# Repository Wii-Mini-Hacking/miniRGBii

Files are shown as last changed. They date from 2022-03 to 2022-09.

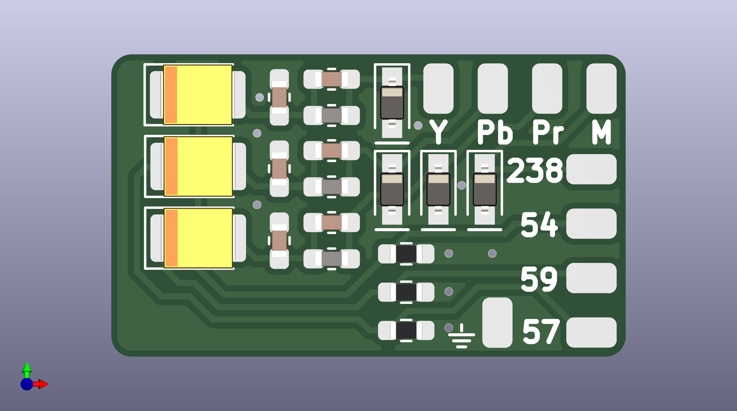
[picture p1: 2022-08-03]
images/miniRGBii_model_front_components.png

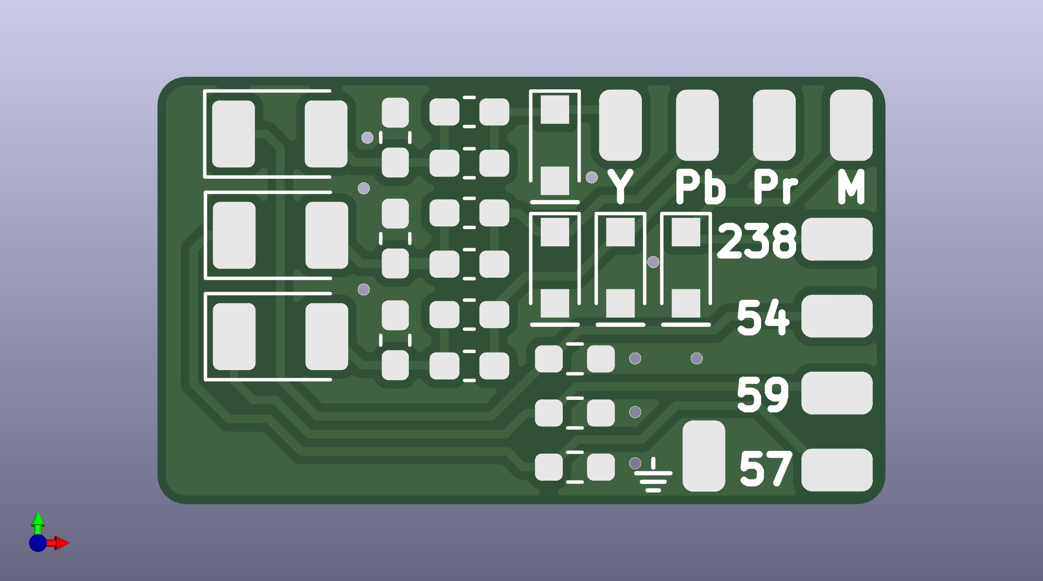
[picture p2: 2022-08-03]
images/miniRGBii_model_front.png

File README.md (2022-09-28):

# miniRGBii
Add-on Board that allows for the re-addition of component video/480p output on a Wii Mini (KiCAD format)

Designed by [@jobfeikens](https://github.com/jobfeikens) and [@Devnol](https://github.com/Devnol)

## Where to buy

You can currently order the miniRGBii directly from Devnol on [Tindie](https://www.tindie.com/products/27985/)

## Installation instructions

You can find instructions on installing the miniRGBii as well as a bunch of other Wii mini mods on [Pimp-My-Mini](https://wii-mini-hacking.github.io/Pimp-My-mini/).

## Fabrication

The board gerber files, Bill of Materials, Pick-and-place and other related documents for fabrication are located in the /output directory.
Gerbers use Protel-style file extensions (compatible with JLCPCB)
Output documents specific to JLCPCB are located in the /output/jlcpcb directory.
If you would like to order the boards from a different manufacturer, you may open a pull request for any manufacturer-specific files to be added.

Original commit tree [here](https://github.com/Devnol/Miini-hwkit)
 
For more information and help visit [the Wii mini Hacking discord server](https://discord.gg/7jNHphfDQk)

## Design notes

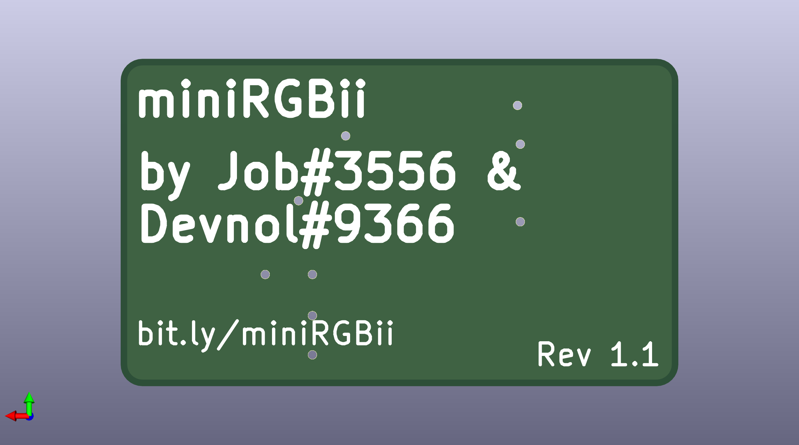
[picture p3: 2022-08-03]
images/miniRGBii_model_rear.png

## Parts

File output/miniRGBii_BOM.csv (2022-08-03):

Source: | /Users/pakou/Documents/CS_Projects/EDA/miniRGBii/miniRGBii.kicad_sch
Date: | Wednesday, 03 August 2022 at 15:16:21
Tool: | Eeschema (6.0.0-0)
Generator: | /Applications/KiCad/KiCad.app/Contents/SharedSupport/plugins/bom_csv_grouped_by_value_with_fp.py
Component Count: | 19
Ref | Qnty | Value | Cmp name | Footprint | Description | Vendor
C64, C69, C84, | 3 | 220μF | C_Polarized | Capacitor_Tantalum_SMD:CP_EIA-3528-12_Kemet-T_Pad1.50x2.35mm_HandSolder | Polarized capacitor
C66, C74, C83, | 3 | 47pF | C | Capacitor_SMD:C_0603_1608Metric_Pad1.05x0.95mm_HandSolder | Unpolarized capacitor
C72, C78, C85, | 3 | 100pF | C | Capacitor_SMD:C_0603_1608Metric_Pad1.05x0.95mm_HandSolder | Unpolarized capacitor
D1, D2, D3, D4, | 4 | PESD5V0U1BA | PESD5V0U1BA | Diode_SMD:D_SOD-323_HandSoldering
FIL15, FIL16, FIL17, | 3 | 390nH | L | Inductor_SMD:L_0603_1608Metric_Pad1.05x0.95mm_HandSolder | Inductor
R37, R39, R40, | 3 | 75Ω | R | Resistor_SMD:R_0603_1608Metric_Pad0.98x0.95mm_HandSolder | Resistor

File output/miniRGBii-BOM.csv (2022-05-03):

Source: | /Users/pakou/Documents/CS_Projects/EDA/miniRGBii/miniRGBii.kicad_sch
Date: | 2022 May 03, Tuesday 18:37:58
Tool: | Eeschema (6.0.0-0)
Generator: | /Applications/KiCad/KiCad.app/Contents/SharedSupport/plugins/bom_csv_grouped_by_value_with_fp.py
Component Count: | 28
Ref | Qnty | Value | Cmp name | Footprint | Description | Vendor
C64, C69, C84, | 3 | 220μF | C_Polarized | Capacitor_Tantalum_SMD:CP_EIA-7343-15_Kemet-W_Pad2.25x2.55mm_HandSolder | Polarized capacitor
C66, C74, C83, | 3 | 50pF | C | Capacitor_SMD:C_0603_1608Metric_Pad1.05x0.95mm_HandSolder | Unpolarized capacitor
C72, C78, C85, | 3 | 100pF | C | Capacitor_SMD:C_0603_1608Metric_Pad1.05x0.95mm_HandSolder | Unpolarized capacitor
D1, D2, D3, D4, | 4 | PESD5V0U1BA | PESD5V0U1BA | Diode_SMD:D_SOD-323_HandSoldering
FIL15, FIL16, FIL17, | 3 | 390nH | L | Inductor_SMD:L_0603_1608Metric_Pad1.05x0.95mm_HandSolder | Inductor
J1, J2, J3, J4, J5, J6, J7, J8, J9, | 9 | Conn_01x01_Male | Conn_01x01_Male | Pad:pad | Generic connector, single row, 01x01, script generated (kicad-library-utils/schlib/autogen/connector/)
R37, R39, R40, | 3 | 75Ω | R | Resistor_SMD:R_0603_1608Metric_Pad0.98x0.95mm_HandSolder | Resistor

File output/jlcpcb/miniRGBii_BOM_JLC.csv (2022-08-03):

Comment | Designator | Footprint | LCSC
220μF | C64,C69,C84 | Capacitor_Tantalum_SMD:CP_EIA-3528-12_Kemet-T_Pad1.50x2.35mm_HandSolder | C79111
47pF | C66,C74,C83 | Capacitor_SMD:C_0603_1608Metric_Pad1.05x0.95mm_HandSolder | C1671
100pF | C72,C78,C85 | Capacitor_SMD:C_0603_1608Metric_Pad1.05x0.95mm_HandSolder | C14858
PESD5V0U1BA | D1,D2,D3,D4 | Diode_SMD:D_SOD-323_HandSoldering | C406223
390nH | FIL15,FIL16,FIL17 | Inductor_SMD:L_0603_1608Metric_Pad1.05x0.95mm_HandSolder | C98095
75Ω | R37,R39,R40 | Resistor_SMD:R_0603_1608Metric_Pad0.98x0.95mm_HandSolder | C4275

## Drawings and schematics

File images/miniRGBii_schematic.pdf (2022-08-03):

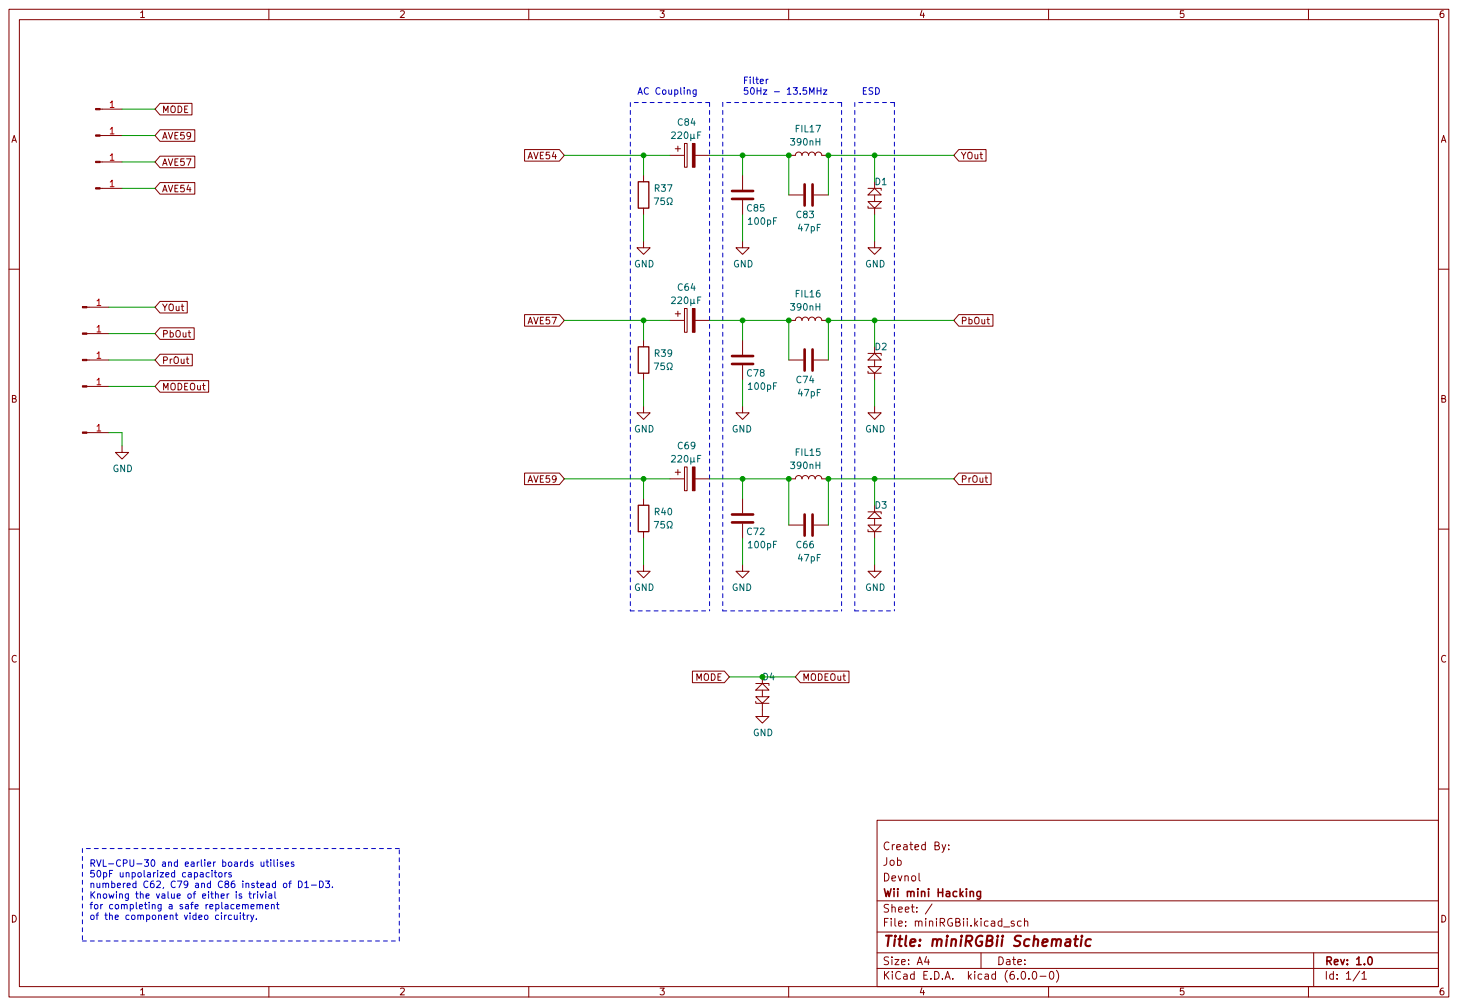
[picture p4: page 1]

File: miniRGBii.kicad_sch Sheet: / Wii mini Hacking Devnol Job Created By:

RVL-CPU-30 and earlier boards utilises 50pF unpolarized capacitors numbered C62, C79 and C86 instead of D1-D3. Knowing the value of either is trivial

for completing a safe replacemement
of the component video circuitry.

Id: 1/1 Title: miniRGBii Schematic

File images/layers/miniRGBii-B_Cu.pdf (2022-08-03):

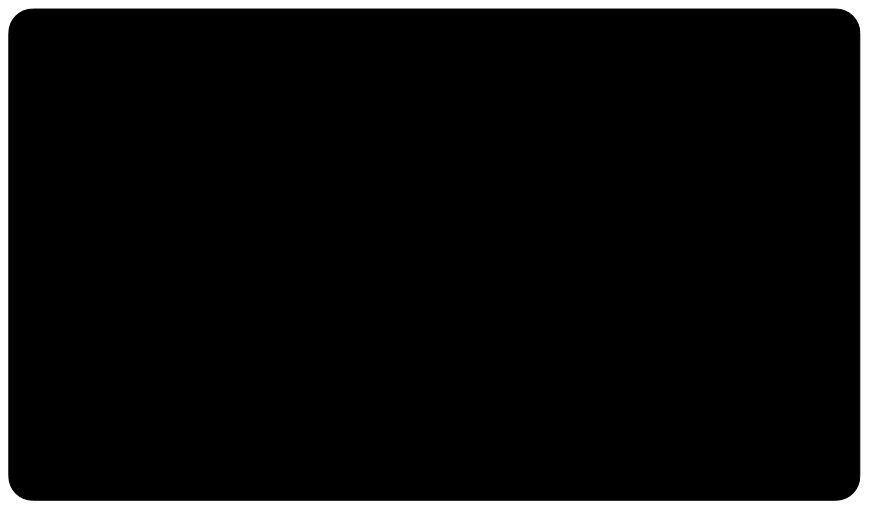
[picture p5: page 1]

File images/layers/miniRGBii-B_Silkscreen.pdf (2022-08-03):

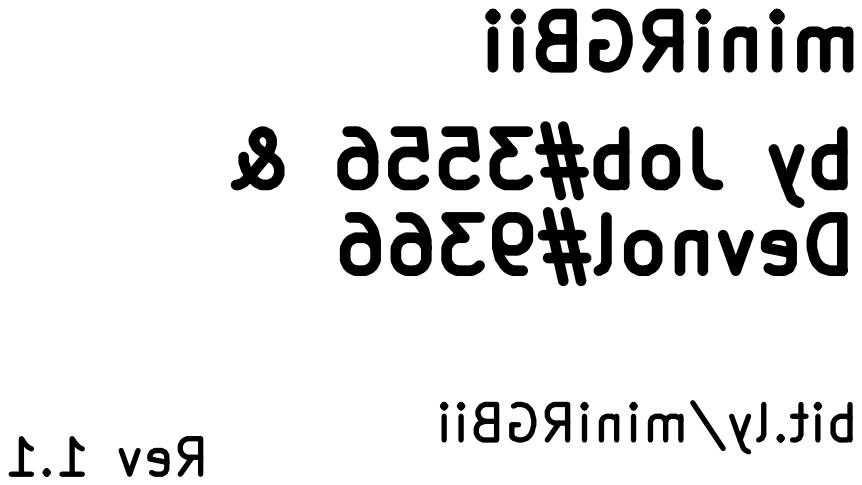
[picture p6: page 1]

bit.ly/miniRGBii Rev 1.1

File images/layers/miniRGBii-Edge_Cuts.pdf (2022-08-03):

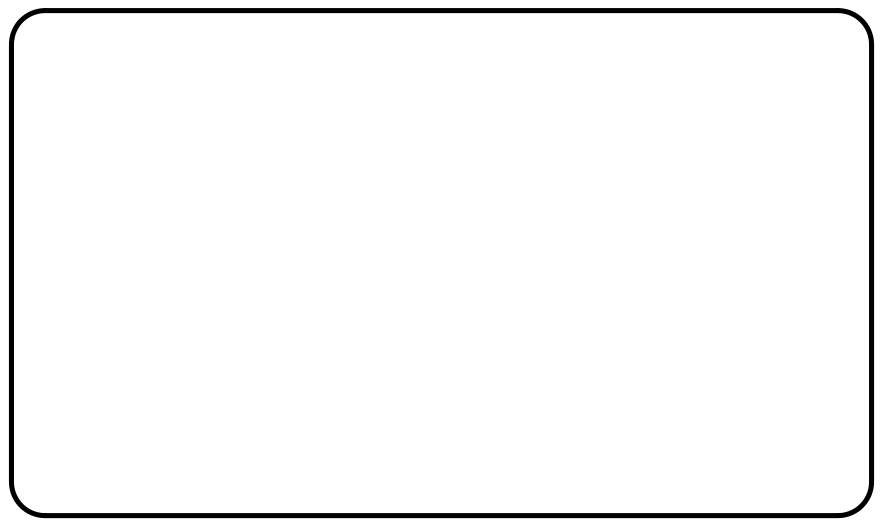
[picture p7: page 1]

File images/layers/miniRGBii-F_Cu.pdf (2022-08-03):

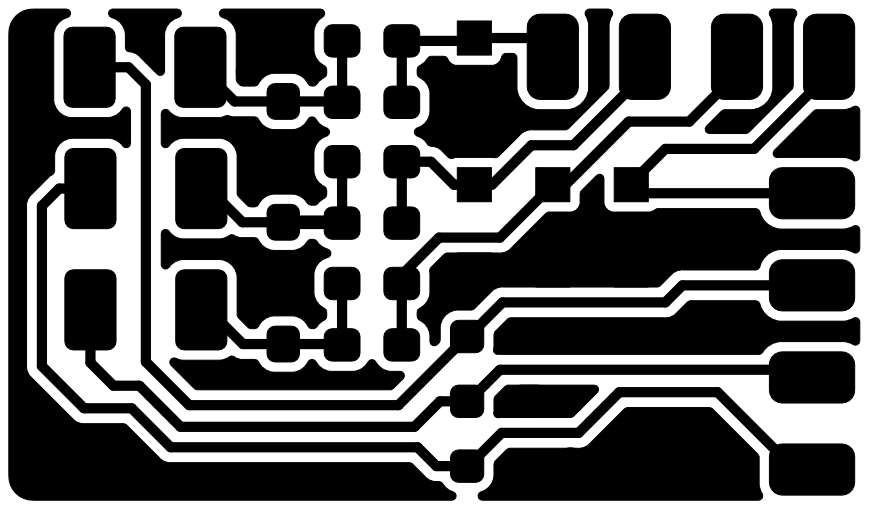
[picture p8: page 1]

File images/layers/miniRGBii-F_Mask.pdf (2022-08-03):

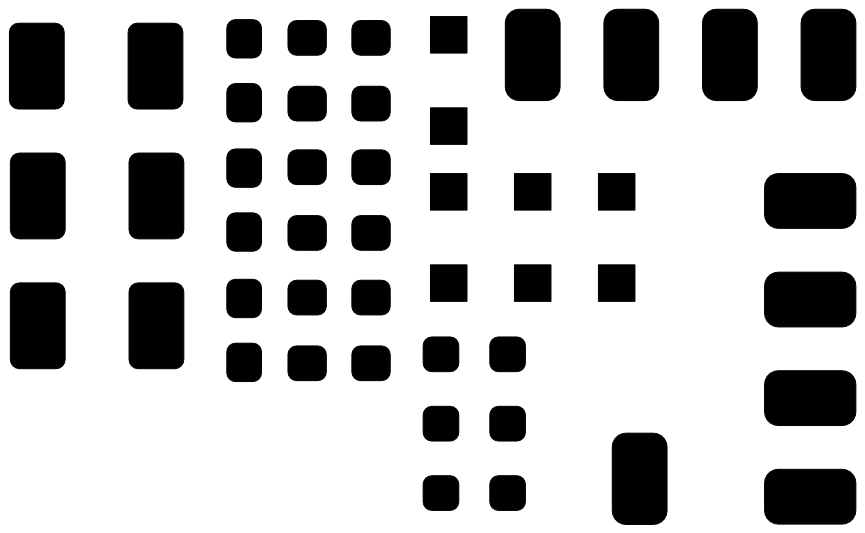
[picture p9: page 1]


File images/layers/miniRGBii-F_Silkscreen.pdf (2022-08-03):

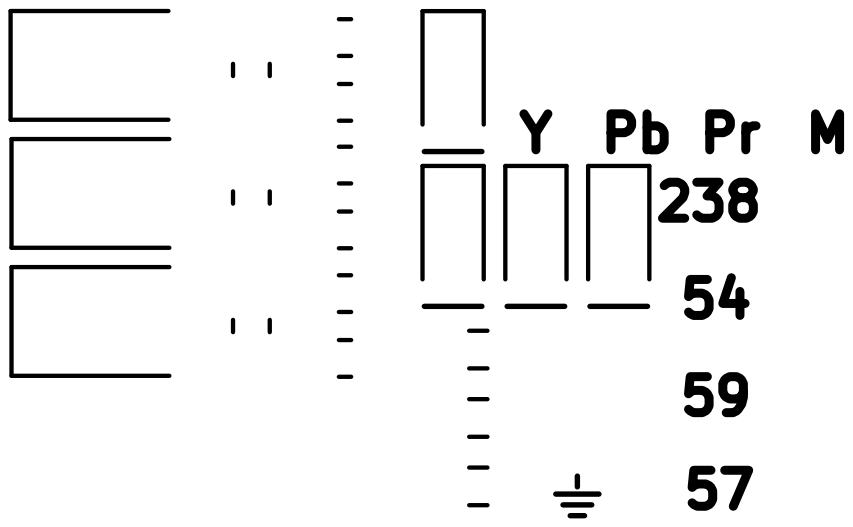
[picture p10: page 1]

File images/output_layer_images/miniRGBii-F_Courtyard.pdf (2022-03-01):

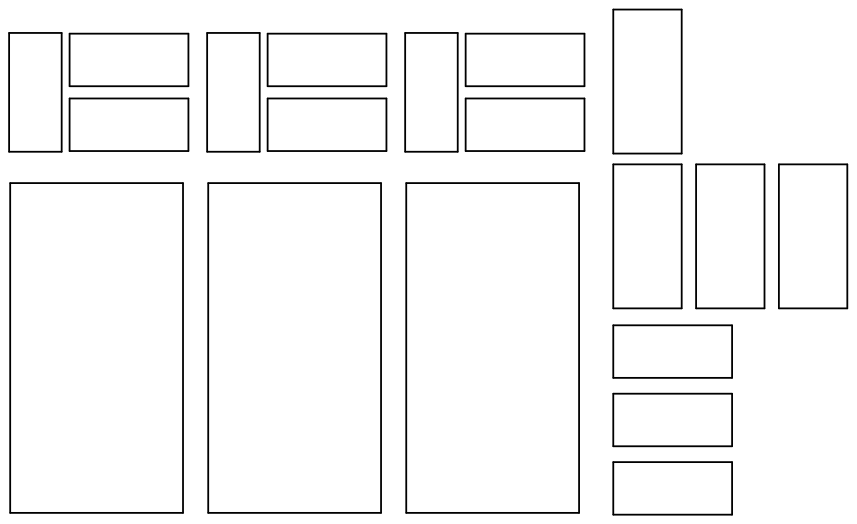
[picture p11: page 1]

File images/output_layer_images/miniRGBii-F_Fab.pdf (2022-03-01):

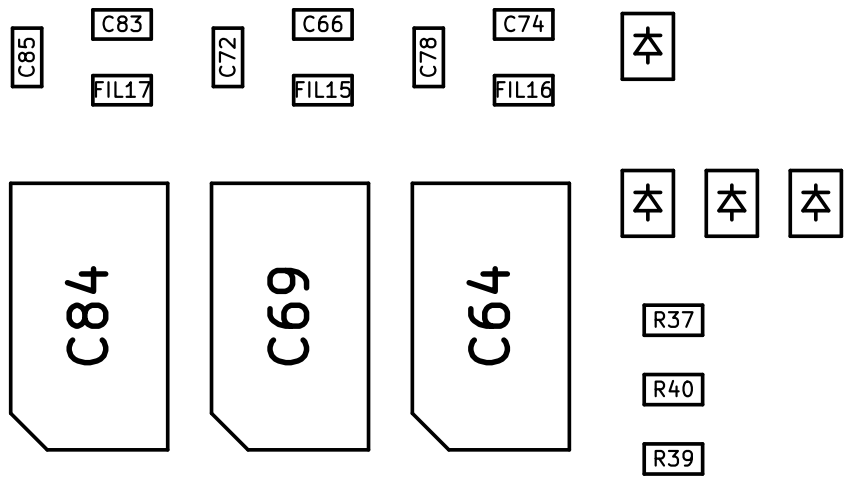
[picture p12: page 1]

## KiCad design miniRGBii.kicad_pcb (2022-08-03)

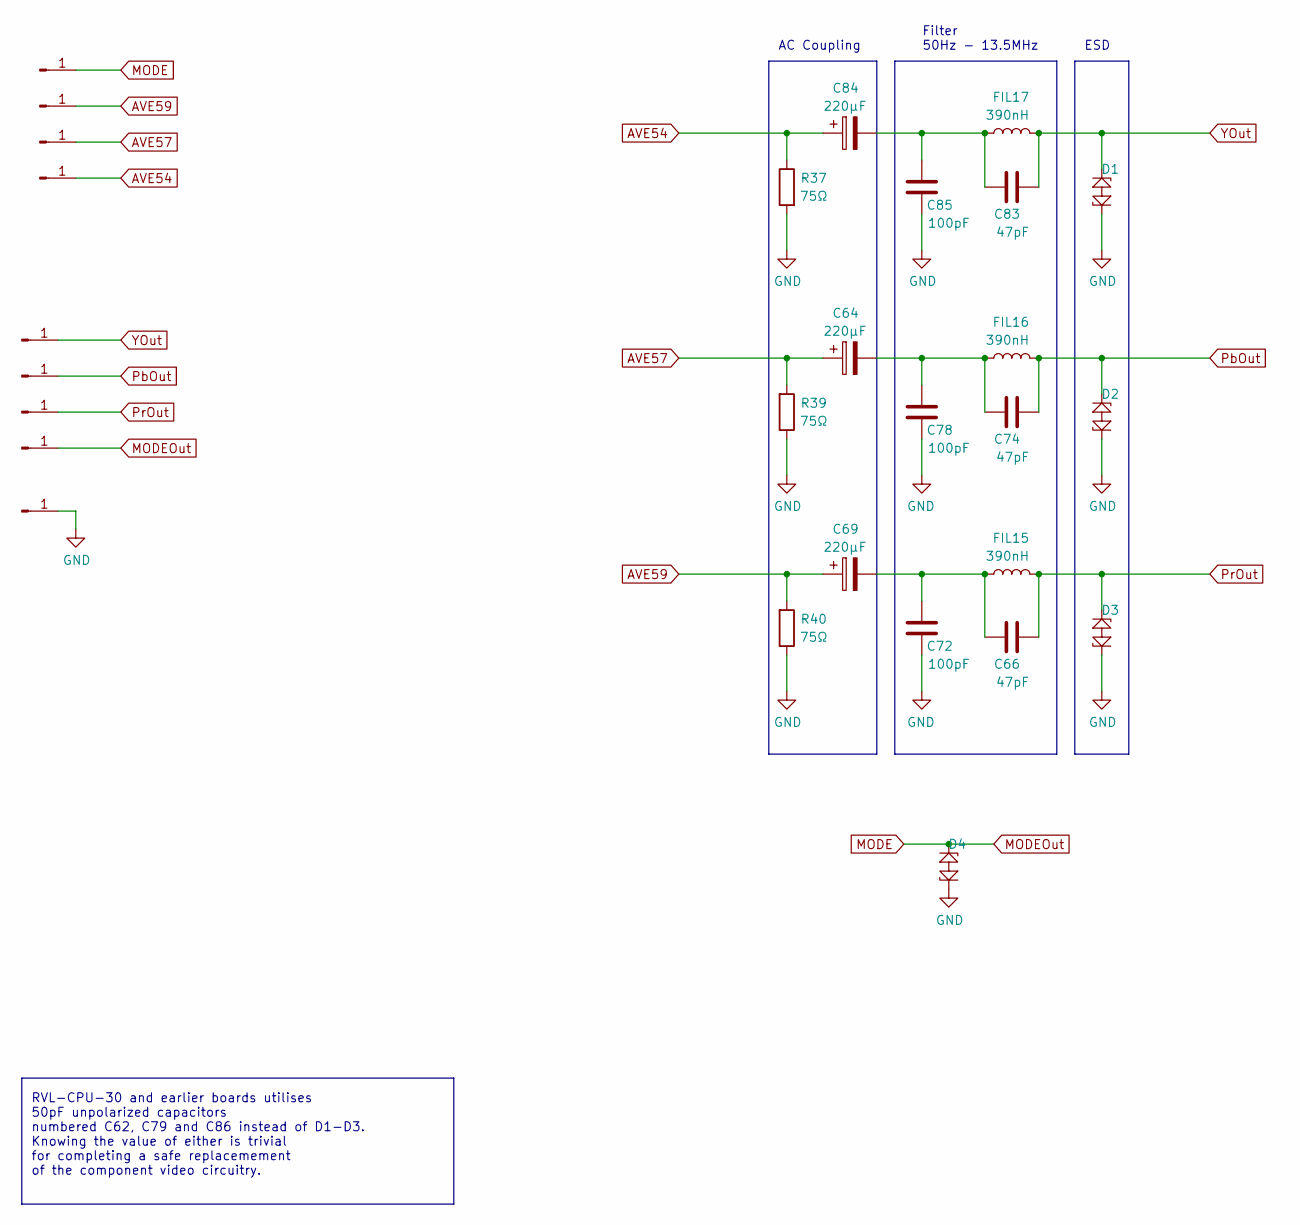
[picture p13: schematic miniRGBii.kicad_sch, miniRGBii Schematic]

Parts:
C64, C69, C84: 220μF; CP_EIA-3528-12_Kemet-T_Pad1.50x2.35mm_HandSolder; LCSC C79111
C66, C74, C83: 47pF; C_0603_1608Metric_Pad1.05x0.95mm_HandSolder; LCSC C1671
C72, C78, C85: 100pF; C_0603_1608Metric_Pad1.05x0.95mm_HandSolder; LCSC C14858
D1, D2, D3: PESD5V0U1BA; D_SOD-323_HandSoldering; LCSC C406223
D4: PESD5V0U1BA; D_SOD-323_HandSoldering
FIL15, FIL16, FIL17: 390nH; L_0603_1608Metric_Pad1.05x0.95mm_HandSolder; LCSC C98095
J1, J2, J3, J4, J5, J6, J7, J8, J9: Conn_01x01_Male; pad
R37, R39, R40: 75Ω; R_0603_1608Metric_Pad0.98x0.95mm_HandSolder; LCSC C4275

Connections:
AVE54: C84.1, J8.1, R37.1
AVE57: C64.1, J7.1, R39.2
AVE59: C69.1, J6.1, R40.2
GND: C72.1, C78.1, C85.1, D1.2, D2.2, D3.2, D4.2, J9.1, R37.2, R39.1, R40.1
MODE: D4.1, J4.1, J5.1
unnamed: C64.2, C74.1, C78.2, FIL16.2
unnamed: C66.1, C69.2, C72.2, FIL15.2
unnamed: C83.1, C84.2, C85.2, FIL17.2
PbOut: C74.2, D2.1, FIL16.1, J2.1
PrOut: C66.2, D3.1, FIL15.1, J3.1
YOut: C83.2, D1.1, FIL17.1, J1.1

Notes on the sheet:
RVL-CPU-30 and earlier boards utilises 50pF unpolarized capacitors numbered C62, C79 and C86 instead of D1-D3. Knowing the value of either is trivial for completing a safe replacemement of the component video circuitry.
Filter 50Hz - 13.5MHz
ESD
AC Coupling

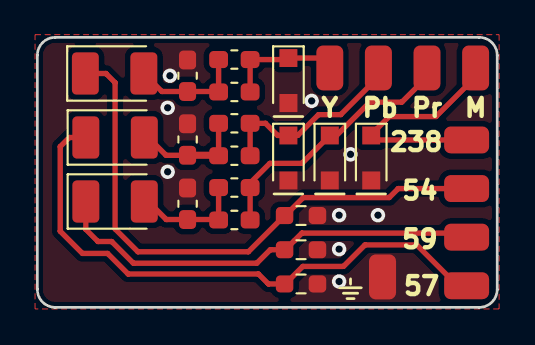
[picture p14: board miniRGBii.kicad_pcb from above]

Board: 2 copper layers, 25.5 x 15.0 mm, 28 parts (0 on the bottom side), 11 nets.

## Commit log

2022-03-01 Import project from https://github.com/Devnol/Miini-hwkit
    [miniRGBii.kicad_pcb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]
2022-03-01 gitignore local kicad backups
2022-05-03 Include Bill Of Materials
    [miniRGBii-BOM.csv, miniRGBii.kicad_sch]
2022-07-09 Change cap footprint to reduce board size
    [miniRGBii.kicad_pcb, miniRGBii.kicad_sch]
2022-08-03 Generate output files and add fab documentation
    [miniRGBi.gbo, miniRGBii-B_Cu.gbl, miniRGBii-B_Mask.gbs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]
